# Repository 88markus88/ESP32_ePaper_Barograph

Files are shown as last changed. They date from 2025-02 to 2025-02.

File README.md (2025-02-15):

# ESP32 ePaper Barograph / Thermograph / Hydrograph
This project is an ESP32 based device that records and displays atmospheric pressure, temperature and humidity using a BME280 sensor and displays them as curves on an 4.2" B/W ePaper display. It operates from a LiPo battery which should be good for 3-6 months on one charge, and can be recharged via USB.
Basic features:
- 4.2" ePaper Display (I am using the display from WeAct, but others with 400x300 resolution are also possible)
- ESP32 Lolin32 Lite module for battery operation, with 1800 mAh LiPo battery intended for 3-6 months operation (not yet tested), charging via USB
- BME280 high quality sensor for pressure, temperature and humidity
- Curves for pressure, temperature, humidity in all combinations
- automatic adjustment of display with independent scales for all 3 measured paramters 
- Time scale can be switched "on the fly" between 21/36/72 hours, while retaining the data that fit into the newly selected time scale
- Tendency display (symbols and numeric) for all 3 measured parameters
- Buzzer can be added, to enable audible alert for large pressure changes and feedback when changing parameters via bluetooth
- Offset for altitude of observation can be enabled and adjusted
- Settings, after activation with button, via bluetooth
- 3D printed housing

## Pictures
Some pictures of the housing and the screen:

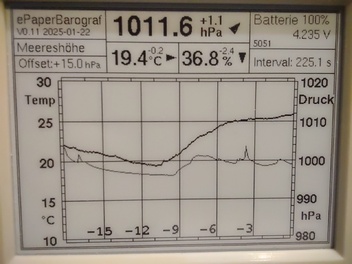
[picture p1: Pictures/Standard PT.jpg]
Display

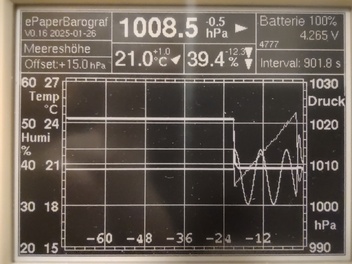
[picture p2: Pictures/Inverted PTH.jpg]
Inverted display

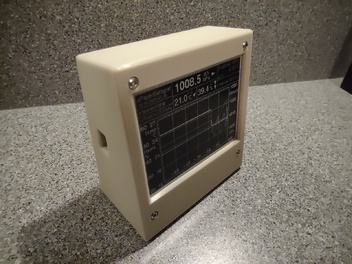
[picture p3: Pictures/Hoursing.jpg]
Housing


## Parts
The project presently supports two devices:
### Lolin32 Lite ESP32 module 
With 4.2" WeAct Display, BME 280 sensor module, 1800 mAh LiPo battery and 3d printed housing. A PCB board is also available.
   The following parts are needed:
   - [Lolin32 Lite ESP32 module](https://www.amazon.de/AZDelivery-LOLIN32-Bluetooth-kompatibel-Arduino/dp/B086V8X2RM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)
   - [BME 280 Module 3.3V](https://www.amazon.de/s?k=bme280&ref=404_search) Make sure that you get a module with 4 pins (6 pins would also work, but not fit into the housing), and from a reliable supplier. Beware: there are many cheap boards on Ebay that in reality do not contain a BME280 (square chip housing), but a BMP280 (rectangular chip housing)
   - [1800 mAh LiPo Battery 52x34x10 mm with JST-PH 2.0 connector](https://www.ebay.de/itm/255510046348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) Other LiPo batteries will also work, but likely not fit into the housing. **ATTENTION** for whatever reason the +/- on the Lolin32 Lite board are not identical to the polarity of most available batteries. **Do not use as delivered, you will likely fry the board!** With a needle you can unlatch the pins in the JST connector, pull out the pins and insert them again in reverse order.
   - JST PH 2.0 ( male & female) connectors. Connectors alsready configured with cables can be used.
   - [4.2" ePaper display module by WeAct](https://de.aliexpress.com/w/wholesale-Weact-studio-ePaper-4.2.html?spm=a2g0o.detail.search.0) 
   - [Elecrow CrowPanel](https://www.elecrow.com/wiki/CrowPanel_ESP32_E-paper_4.2-inch_HMI_Display.html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) with 4.2" ePaper display and BME280 sensor connected to the exposed GPIO pins.
   - 2 Resistors 200 KOhm
   - 1 Pushbutton for hole diameter 7mm
DS18B20, buzzer, transistor are presently not supported and not needed, but can be attached to the PCB
### Elecrow CrowPanel 4.2" ePaper
  - [Elecrow CrowPanel 2.2" e-paper HMI display](https://m.elecrow.com/pages/shop/product/details?id=207653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)
  - [BME 280 Module 3.3V](https://www.amazon.de/s?k=bme280&ref=404_search) Make sure that you get a module with 4 pins (6 pins would also work, but not fit into the housing), and from a reliable supplier. Beware: there are many cheap boards on Ebay that in reality do not contain a BME280 (square chip housing), but a BMP280 (rectangular chip housing). Cables and 2.54 mm pinheader for electrical connection.
   - LiPo Battery 3.7V with Micro JST 1.0 connector. Unfortunately Elecrow has chosen a tiny connector which is rarely used with LiPo batteries. I could not find a battery that comes with this connector, you will have to order battery and connector separately.

## Schematics and PCB
### Lolin32 Lite
I have created a PCB for the project, for use with the Lolin32 Lite module. It permits to connect the Lolin32 Lite module, ePaper, BME280 and battery connectors. It is also possible to add up to 2 DS18B20 temperature sensors and a piezo beeper - both not presently supported by the software. GPIO pins that are not directly used are exposed on a separate connector.
Gerber files are included in this project.
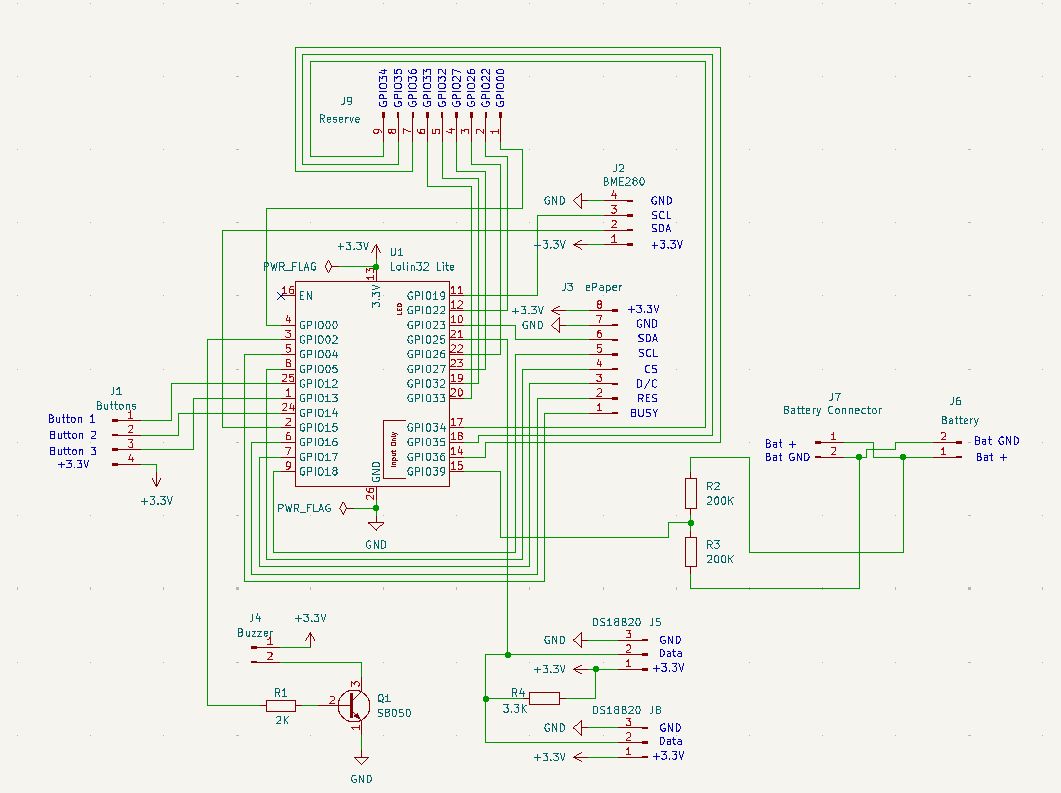
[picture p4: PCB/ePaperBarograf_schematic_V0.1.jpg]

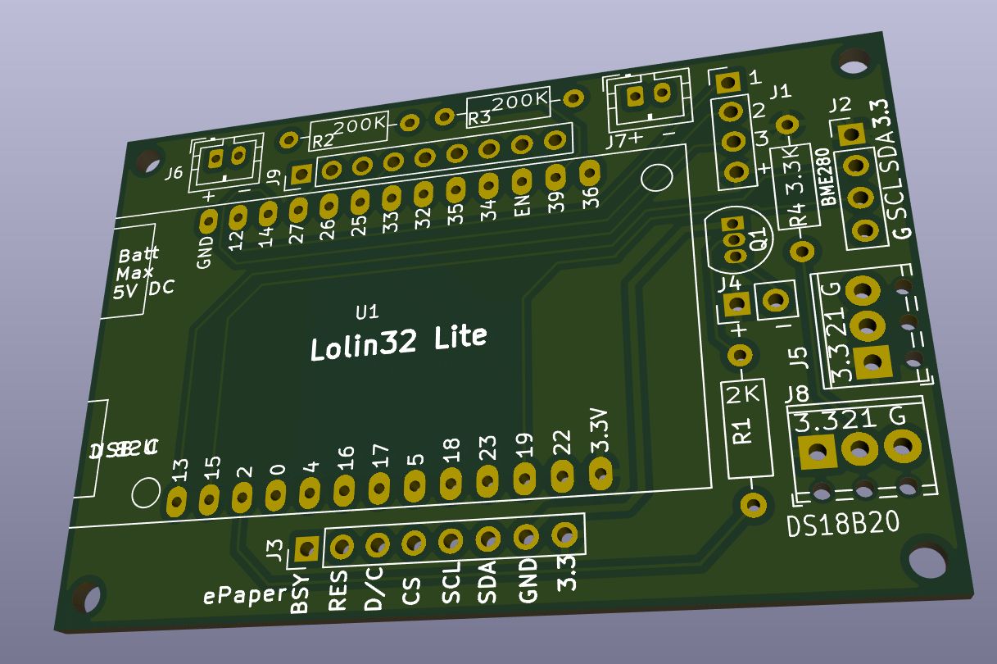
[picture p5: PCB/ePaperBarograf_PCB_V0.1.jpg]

### Elecrow CrowPanel 4.2" ePaper
This handy device can be used as is, with these addtions:
- BME280 (3.3V version) has to be connected via the connector on top to 3.3V, GND and SDA (GPIO15)/ SCL (GPIO19)
- LiPo battery can be connected via "Battery" connector on the left side of the housing. This is optional, without battery you need to keep the system permanently connected to power via USB - with every power loss the history data, which are kept in "RTC memory" are lost. 

## Software
### Software Structure
The software consists of 3 main components, which are located in three .cpp files
1. Control (ePaperBarograf.cpp): Timing, preferences storage, measurement, data storage & recalculations, hibernation
2. Graphics (ePaperGraphics.cpp): Graphics functions for ePaper display
3. Bluetooth configuration (ePaperBluetooth.cpp): Serial Bluetooth functions for adjustment of settings. Serial Bluetooth can only be used with the Lolin32 Lite - the CrowPanel has an ESP32S3 which only supports Bluetooth Low Energy (BLE).
4. BLE configuation - presently experimental and not yet functional
### Libraries
- OneWire                  : needed for BME280
- Arduino Unified Sensor   : needed for BME280
- Arduino BME280           : needed for BME280
- GxEPD2                   : ePaper Graphics
- Dallas Temperature       : DS18B20 temperature sensor
- u8g2 for Adafruit        : Fonts
### Building the Software
The software is written in C++, platform is Arduino and development environment is Platformio with VSCode. 
platformio.ini contains two development environments:
- env:Lolin32Lite_ePaper - this is the environment used for the Lolin32 Lite with separate 4.2" ePaper and battery. 
- env:CrowPanel_42 - this is the environment used for the Elecrow CrowPanel 4.2" ePaper.
Just connect your ESP32 to the computer via USB, select the env for the system you are building for and start the build. Platformio will automatically load the libraries that are needed and upload the firmware via USB Port. 
Switching of environments is done by clicking on the "env:..." entry in the lower status bar of VSCode, and then selecting the environment in the list that is displayed on top. Switching takes a few seconds.
Note that two versions of the hardware board are used, which have slightly different pinouts. Inparticular, in prototypes with hand mande board GPIO 35 is used for measurement of the battery voltage. In the newer printed circuit boards, GPIO 39 is used. This must be taken into account by setting either -D HANDMADE_BOARD or -D PCB_BOARD in [env] section within platformio.ini. Just comment out the part not needed.
### Starting the Barograph
After final assembly and test of all parts the software needs to be flashed on the ESP32. This is done by connecting the device the deveopment computer via USB cable and using the "Build" feature of platformio.
Once the software has been flashed, it will begin to operate directly:
- Default parameters are written into the ESP32 preferences memory (flash), which survies power down and even flashing of a new sofware version
- Test data are created, stored in RTC memory and displayed. They consist of artificial curves, which are easy to recognize and overwritten by real measured data as they are created. Complete overwrite of all test data takes 21 hours in default settings, up o 84 hours if the maximum time setting is used. 
Note that RTC memory content survives the sleep period between two measurements, but not power down (battery disconnected) or flashing of new software
- The barograf will then start routine operation- In default settings the measuring range is 18 hours, Pressure, Temperature and Humidiy are displayed. If more than 1 curve is shown, each has it's own scale. he further right a scale is on the screen, the thicker the corresponding curve If, e.g., Pm T and H are displayed, the pressure curve is 3 pixels, the temperature curve 2 pixels and the humidity curve one pixel.
### Settings
Settings are adjusted via Bluetooth connection. There is no special app for this, please use a bluetooth terminal on a mobile device with Bluetooth. A good tool for this is the [Serial Bluetooth Terminal by Kai Morich](https://play.google.com/store/apps/details?id=de.kai_morich.serial_bluetooth_terminal&hl=de)
This is how it is done:
- The Barograf is set into settings mode by presing the button. A corresponding message is shown on the screen
- Connect the mobile device to the barograph using the bluetooth settings. This has to be done only once
- Connect the Bluetooth terminal to the barograph, using the list of available devices in the "Hamburger" menu
- The barograph will then send a list of available commands 
- Enter the desired command. 
Examples: 
ATI to invert the display
ATC,1 to enable pressure correction (add the correction value)
ATX to leave the bluetooth settings and restart measurements
- Exit bluetooth settings 
If no command is given, the barograph will revert to measurement mode after 60 seconds
## Open topics
- BLE functionality to allow setting of parameters for CrowPanel
- Bluetooth setting for Lolin32 Lite is presently only possible via Bluetooth terminal on a mobile device. Create App or BLE web page to allow easier configuration

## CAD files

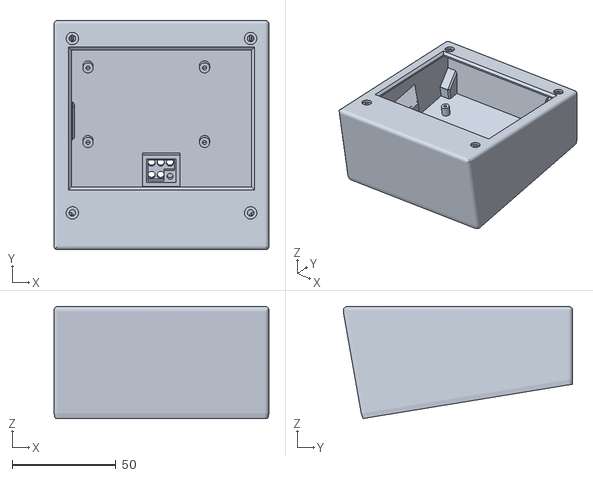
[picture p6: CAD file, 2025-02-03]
STL/Wetterstation WeAct epaper 4.2 v23.stl
103.8 x 110.8 x 54.1

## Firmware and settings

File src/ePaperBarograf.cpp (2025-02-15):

/****************************************************************/
// ePaperBarograf by. M. Preidel
/****************************************************************/

#include <Arduino.h>
#include <math.h>

//**** ESP32 sleep and rtc memory (which survives deep sleep)
#include "esp_sleep.h"
#include "driver/rtc_io.h"

//*** libs and defines for BME280
#include <Wire.h>
#include <Adafruit_Sensor.h>
#include <Adafruit_BME280.h>

// *** lib for permanent data storage in EEPROM
// https://randomnerdtutorials.com/esp32-save-data-permanently-preferences/
// if these defines are set, preferences are written / saved to eeprom. 
// otherwise just from RTC storage (survives deep sleep)
#define WRITE_PREFERENCES
#define WRITE_PREFS_INTERVAL 250 // store counters into preferences every <x> run
#define READ_PREFERENCES
#include <Preferences.h>
Preferences preferences; // object for preference storage in EEPROM
#define prefIDENT "barograf1"

// header file mit #defines, forward declarations, "extern" declarations von woanders deklarierten globalen var's
// globale variablen und alle anderen #includes sind im .cpp file
#include "ePaperBarograf.h"
#include "global.h" // global stuff from other modules

//************ push button stuff *****************/
struct Button {
  const uint8_t PIN;
  uint32_t numberKeyPresses;
  bool pressed;
};

#ifdef isPushButtons
  #ifdef LOLIN32_LITE
    #define BUTTON1 GPIO_NUM_12   // upper black button
    #define BUTTON2 GPIO_NUM_14  // middle red button
    #define BUTTON3 GPIO_NUM_13  // lower red  button
  #endif
  #ifdef CROW_PANEL  
    #define BUTTON1 GPIO_NUM_2  // upper button MENU
    #define BUTTON2 GPIO_NUM_1  // lower button EXIT
    #define BUTTON3 GPIO_NUM_5  // button CONFIRM at rotary switch
    #define BUTTON4 GPIO_NUM_4  // button DOWN at rotary switch
    #define BUTTON5 GPIO_NUM_6  // button DOWN at rotary switch
  #endif  
  volatile Button button1 = {BUTTON1, 0, false};
  volatile Button button2 = {BUTTON2, 0, false};
  volatile Button button3 = {BUTTON3, 0, false};

  void ARDUINO_ISR_ATTR button1Handler();
  void ARDUINO_ISR_ATTR button2Handler();
  void ARDUINO_ISR_ATTR button3Handler();
#endif // isPushButtons

// GPIO definition for battery voltage reading
#ifdef HANDMADE_BOARD
  #define VOLTAGE_PIN 35
#endif 
#ifdef PCB_BOARD
  #define VOLTAGE_PIN 39
#endif 

// GPIO definition for buzzer
#define BUZZER_PIN 2

// 08.01.25: store these variables in RTC memory, which survives deep sleep. 
RTC_DATA_ATTR uint32_t startCounter = 0;    // total counter for starts of ESP32
RTC_DATA_ATTR uint32_t dischgCnt = 0;    // counter for starts of ESP32 since last charge
RTC_DATA_ATTR uint32_t prevMicrovolt = 0;
RTC_DATA_ATTR float prevVoltage = 0;
float prefs[4] = {0.0, 0.0, 0.0, 0.0};  // storage for preferences

float volt, percent;                    // battery voltage and percent fill degree

uint32_t multiplier = MULTIPLIER_FULL;  // slepp time multiplier (standard is 1 min, this multiplier is applied to that)
//uint32_t targetSleepSec;                // target sleep time in seconds
uint32_t targetSleepUSec;               // target sleep time in microseconds

char outstring[maxLOG_STRING_LEN];      // for serial and other debug output

Adafruit_BME280 bme;                    // BME280 sensor I2C
float temperature = 0;                  // data read by BME280
float humidity = 0;
float pressure = 0;


//----------------------- measurement data variables -----------------------
uint32_t startTimeMillis; 
uint32_t measTimeMillis;

// measurement data

#define createTestData          // flag to create test data at setup, overwriting whatever may be there

// measurement data, stored in RTC memory which survives the deep sleep. ESP32 has 8 K, used for this 5448 Bytes
RTC_DATA_ATTR measurementData wData;

// screen colors
RTC_DATA_ATTR uint32_t fgndColor;
RTC_DATA_ATTR uint32_t bgndColor;

// determine after how many partial updates a full update of the epaper is to be done
// 1: always full update
#ifdef LOLIN32_LITE
  #define FULL_UPDATE_INTERVAL  10
#endif
#ifdef CROW_PANEL
  #define FULL_UPDATE_INTERVAL  1
#endif

/**************************************************!
   @brief    buzzer()
   @details  Function to create a buzzer sound
   @param    uint16_t number    : how many buzzes
   @param    uint16_t duration : how long in ms for every buzz
   @param    uint16_t interval : how long in ms between buzzes
   @return   void
***************************************************/
void buzzer(uint16_t number, uint16_t duration, uint16_t interval)
{
  uint16_t i;
  for(i=0; i<number; i++){
    logOut(3, (char*)"Start Buzzer");
    pinMode(BUZZER_PIN, OUTPUT);
    digitalWrite(BUZZER_PIN, HIGH);
    delay(duration);
    digitalWrite(BUZZER_PIN, LOW);
    delay(interval);
    logOut(3, (char*)"End of Buzzer");
  }  
}    

/**************************************************!
   @brief    logOut()
   @details  Function create log output
   @return   void
***************************************************/
void logOut(int logLevel, char* str)
{
  char safeStr[maxLOG_STRING_LEN+10];
  static uint32_t logCnt = 0;
  // for safety: ensure zero termination well before the end of the string
  // crashes with static strings.
  // str[maxLOG_STRING_LEN-1]=0;
  if(logLevel <= logLEVEL){
    strncat(safeStr, str, maxLOG_STRING_LEN-1); // copy limited number of characters only
    sprintf(safeStr,"%ld %s",logCnt,str);
    //Serial.println(str);
    Serial.println(safeStr);
    logCnt++;
  }
}

/**************************************************!
   @brief    Function to read the BME280 data 
   @details  The BME280 data is read in 
   @return   void
***************************************************/
void getBME280SensorData() 
{
  // Only needed in forced mode! Forced mode lets the sensor sleep between measurements.
  // normal mode: sensor warming +1,5°C vs. DS18B20. Forced mode: +0,9°C
  bme.takeForcedMeasurement(); // has no effect in normal mode

  pressure = bme.readPressure()/100;
  sprintf(outstring,"Pressure: %3.1f mBar ", pressure);
  logOut(2, outstring);
  humidity = bme.readHumidity();
  sprintf(outstring,"Humidity: %3.1f %% ", humidity);
  logOut(2, outstring);
  temperature = bme.readTemperature();
  sprintf(outstring,"Temperature: %3.1f °C \n", temperature);
  logOut(2, outstring);
}  // of method "getSensorData()"


/*************************** getBatteryCapacity ************************** */
int readBatteryVoltage(float* percent, float* volt)
{
  uint16_t readval;

  *percent = 100;
  pinMode(VOLTAGE_PIN, INPUT);
  readval = analogRead(VOLTAGE_PIN);// / 4096.0 * 7.23;      // LOLIN D32 (no voltage divider need already fitted to board.or NODEMCU ESP32 with 100K+100K voltage divider
  *volt= (float)readval / 4096.0 * 7.23;
  //float voltage = analogRead(39) / 4096.0 * 7.23;    // NODEMCU ESP32 with 100K+100K voltage divider added
  //float voltage = analogRead(A0) / 4096.0 * 4.24;    // Wemos / Lolin D1 Mini 100K series resistor added
  //float voltage = analogRead(A0) / 4096.0 * 5.00;    // Ardunio UNO, no voltage divider required
  
  *percent = 2808.3808 * pow(*volt, 4) - 43560.9157 * pow(*volt, 3) + 252848.5888 * pow(*volt, 2) - 650767.4615 * *volt + 626532.5703;
  
  if(*percent<0) *percent =0; // to ensure that the above formula does not produce negative values, as it does slightly above 3.5V

  if (*volt > 4.19) *percent = 100;
  else if (*volt <= 3.50) *percent = 0;

  sprintf(outstring," readval: %d Voltage: %3.2f Percent: %3.1f\n",readval, *volt,*percent);
  logOut(2,outstring);
  return(true);
}

/*************************  fillTestData ******************************************/
// fill the measurement arrays with arbitrary demo data to test graphics routine

void fillTestData()
{
  int i, j;
  float startval = 1017.0;
  float randomspread = 2.0;
  float cosrange = 5.0;

  logOut(2,(char*)"Filling test data");

  wData.pressHistoryMax= - 1000000;
  wData.pressHistoryMin=   1000000;
  wData.tempHistoryMax= - 1000000;
  wData.tempHistoryMin=   1000000;
  wData.humiHistoryMax=   0;      // unsigned integer
  wData.humiHistoryMin=   10000;

  // TEST - remove next 3 lines for working version. Overwrites preferences every time when recompiled!
  wData.targetMeasurementIntervalSec = d_measIntervalSec;
  wData.graphTimeRangeHours = d_timeRangeHours;
  wData.preferencesChanged = true;
  wData.indexFirstPointToDraw = offsetData72hGraph;
  wData.graphicsType = d_graphicsType;
  //if(wData.applyPressureCorrection) 
  //  wData.applyPressureCorrection = true;
  //  wData.pressureCorrValue = 15.0;
  gettimeofday(&wData.last2MeasurementTimestamp, NULL);    // get&set previous measurement time
  delay(2000);
  gettimeofday(&wData.lastMeasurementTimestamp, NULL);     // get&set act measurement time
  wData.lastTargetSleeptime = wData.targetMeasurementIntervalSec;
  wData.lastActualSleeptimeAfterMeasUsec = 0; // we have not slept yet. causes measurement ot be started immediately in doWork()
  delay(500);                                // this brings us beyond the 5 sec threshold in doWork()

  sprintf(outstring,"************** fill test data %d ********************\n", wData.dataPresent);
  logOut(2,outstring);
  for(i=0;i<noDataPoints;i++)
  {
    wData.ageOfDatapoint[i] = (noDataPoints-i) * wData.targetMeasurementIntervalSec; // default spacing: 15 min = 900 sec
    wData.pressHistory[i]= 994 + 40/(i+1);
    //wData.pressHistory[i]= 1030-(float)i/20;
    //wData.pressHistory[i]= startval+(float)cos((float)i/50)*cosrange + i/70 + randomspread*((float)rand()/ RAND_MAX - 1.5);
    if(wData.pressHistory[i] > wData.pressHistoryMax) 
        wData.pressHistoryMax = wData.pressHistory[i];
    if(wData.pressHistory[i] < wData.pressHistoryMin) 
        wData.pressHistoryMin = wData.pressHistory[i];    

    wData.tempHistory[i] = 20 + 2*sin((float)i/20);
    if(wData.tempHistory[i] > wData.tempHistoryMax) 
        wData.tempHistoryMax = wData.tempHistory[i];
    if(wData.tempHistory[i] < wData.tempHistoryMin) 
        wData.tempHistoryMin = wData.tempHistory[i]; 

    wData.humiHistory[i] = int(10.0*(35.5 + 20 * i / noDataPoints+ randomspread*((float)rand()/ RAND_MAX - 1.5))); 
    if(wData.humiHistory[i] > wData.humiHistoryMax) 
        wData.humiHistoryMax = wData.humiHistory[i];
    if(wData.humiHistory[i] < wData.humiHistoryMin) 
        wData.humiHistoryMin = wData.humiHistory[i];      
  }

  sprintf(outstring,"Min/Max Tstdata: P: %3.1f-%3.1f T:  %3.1f-%3.1f H: %d-%d", 
        wData.pressHistoryMin, wData.pressHistoryMax,  wData.tempHistoryMin,  wData.tempHistoryMax,
        wData.humiHistoryMin, wData.humiHistoryMax);
  logOut(2,outstring);  
  sprintf(outstring,"Tstdata: Time: %ld.%06ld sec", 
        wData.lastMeasurementTimestamp.tv_sec, wData.lastMeasurementTimestamp.tv_usec);
  logOut(2,outstring);  

  // 3 hour pressure change value: minus 3h = 12 data points at 15 min per point
  wData.pressure3hChange = wData.pressHistory[noDataPoints-1]-wData.pressHistory[noDataPoints-1-12];
  wData.humidity3hChange = wData.humiHistory[noDataPoints-1]-wData.humiHistory[noDataPoints-1-12];
  wData.temperature3hChange=wData.tempHistory[noDataPoints-1]-wData.tempHistory[noDataPoints-1-12];

  // actual data for initial display
  wData.actPressureRaw = wData.pressHistory[noDataPoints-1];
  wData.actPressureCorr= wData.actPressureRaw + wData.pressureCorrValue;
  wData.actHumidity    = wData.humiHistory[noDataPoints-1];
  wData.actTemperature = wData.tempHistory[noDataPoints-1];

  // set marker for "data present" to avoid calling this function again.
  wData.dataPresent = true;

  //set marker for "just initialized"
  wData.justInitialized = true;
}

/**************************************************!
   @brief    Function to calculate the pressure, temperature,humdity change during the last 3 hours 
   @details  using the time information in wData.ageOfDatapoint[i]
   @return   void
***************************************************/
void calc3HourChanges()
{
  int i, marker;
  uint32_t threeHourMark = 3*3600;
  float newP, oldP, oldT, newT, oldH, newH;

  for (i=noDataPoints-1; i>0; i--)
  {
    if ((wData.ageOfDatapoint[i]-threeHourMark) < wData.targetMeasurementIntervalSec/2)
    {
      marker=i;
      break;
    }
  }

  //calculate average over three data points for now and three hours ago, changed to only one last point
  oldP = (wData.pressHistory[marker-1] + wData.pressHistory[marker] + wData.pressHistory[marker+1])/3;
  //newP = (wData.pressHistory[noDataPoints-1]+wData.pressHistory[noDataPoints-2]+wData.pressHistory[noDataPoints-3])/3;
  newP = wData.pressHistory[noDataPoints-1];
  wData.pressure3hChange =  newP - oldP;

  //same for humidity
  oldH = (wData.humiHistory[marker-1] + wData.humiHistory[marker] + wData.humiHistory[marker+1])/3;
  // newH = (wData.humiHistory[noDataPoints-1]+wData.humiHistory[noDataPoints-2]+wData.humiHistory[noDataPoints-3])/3;
  newH = wData.humiHistory[noDataPoints-1];
  wData.humidity3hChange =  (float)(newH - oldH)/10.0;

  //and temperature
  oldT = (wData.tempHistory[marker-1] + wData.tempHistory[marker] + wData.tempHistory[marker+1])/3;
  //newT = (wData.tempHistory[noDataPoints-1]+wData.tempHistory[noDataPoints-2]+wData.tempHistory[noDataPoints-3])/3;
  newT = wData.tempHistory[noDataPoints-1];
  wData.temperature3hChange =  newT - oldT;

  //previous simplified method, on point and assuming 900 sec per data point
  //wData.pressure3hChange = wData.pressHistory[noDataPoints-1]-wData.pressHistory[noDataPoints-1-12];
  sprintf(outstring, "3h:%d t:%ld Pold:%3.2f Pnew:%3.2f 3hC:%3.3f Told:%3.2f, Tnew:%3.2f 3hC:%3.3f Hold:%3.2f Hnew:%3.2f 3hC:%3.3f\n",
      marker, wData.ageOfDatapoint[marker], 
      oldP, newP, wData.pressure3hChange, 
      oldT, newT, wData.temperature3hChange,
      oldH, newH, wData.humidity3hChange);
  logOut(2,outstring);    
}

/**************************************************!
   @brief    output the stored data
   @details  intended to check the work of the data timescale change functions
   @param    l_idx, u_idx: control start and end ranges
   @return   void
***************************************************/
void outputStoredData(uint16_t l_idx, uint16_t u_idx)
{
  int i; 

  for(i=0;i<noDataPoints;i++){
    if(i <= l_idx || i >= u_idx){
      //sprintf(outstring,"i: %d, age %ld time_sec: %ld P: %3.1f T: %3.1f H: %3.1f",
      sprintf(outstring,"i: %d, age %ld P: %3.1f H: %d H: %3.1f",
        i, wData.ageOfDatapoint[i], //wData.timestampSecondsOfDataPoint[i],
        wData.pressHistory[i], wData.humiHistory[i], wData.tempHistory[i]);
      logOut(2,outstring)  ;
    }  
  }

}

/**************************************************!
   @brief    quarterMeasurementScale() : 84->21
   @details  Adapting the stored measurement data and the measurement interval
   @param
   @return   void
***************************************************/
void quarterMeasurementScale()
{
  int16_t i, idx;
  uint32_t interv;

  sprintf(outstring,"Before quarterMScale: wData.targetMeasurementIntervalSec: %ld",  wData.targetMeasurementIntervalSec);
  logOut(2,outstring);

  //outputStoredData(5, noDataPoints-5); // limited ouput
  outputStoredData(noDataPoints, 0);   // output all 

  // adapt measurement interval
  wData.targetMeasurementIntervalSec = wData.targetMeasurementIntervalSec/4; // controls proper time planning
  wData.lastTargetSleeptime = wData.targetMeasurementIntervalSec;            // to ensure proper time planning for next measurement 
  wData.actSecondsSinceLastMeasurement = wData.actSecondsSinceLastMeasurement/4; // only for display
  wData.lastActualSleeptimeAfterMeasUsec = wData.lastActualSleeptimeAfterMeasUsec/4; // needed for sleep time calculation
  wData.lastActualSleeptimeNotMeasUsec   = wData.lastActualSleeptimeNotMeasUsec /4;  // needed for sleep time calculation
  interv =  wData.targetMeasurementIntervalSec;
  idx=0;
  for(i=3*noDataPoints/4; i<noDataPoints; i++){
    if(idx<30 || idx > (noDataPoints-10))
    {
      sprintf(outstring, "idx: %d i: %d age[idx, i] %ld %ld: P[idx, i]: %3.1f %3.1f", 
        idx, i, wData.ageOfDatapoint[idx], wData.ageOfDatapoint[i],
        wData.pressHistory[idx], wData.pressHistory[i]);
      logOut(2,outstring);
    }  
    wData.ageOfDatapoint[idx]             = wData.ageOfDatapoint[i];
    //wData.timestampSecondsOfDataPoint[idx]= wData.timestampSecondsOfDataPoint[i];
    wData.pressHistory[idx]               = wData.pressHistory[i];
    wData.humiHistory[idx]                = wData.humiHistory[i];
    wData.tempHistory[idx]                = wData.tempHistory[i];
    idx++;
    wData.ageOfDatapoint[idx]             = wData.ageOfDatapoint[i] + interv;
    //wData.timestampSecondsOfDataPoint[idx]= wData.timestampSecondsOfDataPoint[i];
    wData.pressHistory[idx]               = wData.pressHistory[i];
    wData.humiHistory[idx]                = wData.humiHistory[i];
    wData.tempHistory[idx]                = wData.tempHistory[i];
    idx++;
    wData.ageOfDatapoint[idx]             = wData.ageOfDatapoint[i] + 2 * interv; 
    //wData.timestampSecondsOfDataPoint[idx]= wData.timestampSecondsOfDataPoint[i];
    wData.pressHistory[idx]               = wData.pressHistory[i];
    wData.humiHistory[idx]                = wData.humiHistory[i];
    wData.tempHistory[idx]                = wData.tempHistory[i];
    idx++;
    wData.ageOfDatapoint[idx]           = wData.ageOfDatapoint[i] + 3 * interv;
    //wData.timestampSecondsOfDataPoint[idx]= wData.timestampSecondsOfDataPoint[i];
    wData.pressHistory[idx]               = wData.pressHistory[i];
    wData.humiHistory[idx]                = wData.humiHistory[i];
    wData.tempHistory[idx]                = wData.tempHistory[i];
    idx++;    
  }

  // correct nominal ages of data points, required for graphics display - correct x axis
  idx = 0;
  for(i=(noDataPoints-1); i>=0 ; i--){
     wData.ageOfDatapoint[i] = idx * wData.targetMeasurementIntervalSec;
     idx++;
     //sprintf(outstring,"i: %d idx: %d", i, idx);
     //logOut(2,outstring);
  } 

  sprintf(outstring,"After quarterMScale: wData.targetMeasurementIntervalSec: %ld",  wData.targetMeasurementIntervalSec);
  logOut(2,outstring);
  //outputStoredData(5, noDataPoints-5); // limited ouput
  outputStoredData(noDataPoints, 0);   // output all 
}

/**************************************************!
   @brief    halfMeasurementScale() : 42->21 or 84->42h
   @details  Adapting the stored measurement data and the measurement interval
   @param
   @return   void
***************************************************/
void halfMeasurementScale()
{
  int16_t i, idx;
  uint32_t interv;

  sprintf(outstring,"Before halfMScale: wData.targetMeasurementIntervalSec: %ld",  wData.targetMeasurementIntervalSec);
  logOut(2,outstring);
  //outputStoredData(5, noDataPoints-5); // limited ouput
  outputStoredData(noDataPoints, 0);   // output all 

  // adapt measurement interval
  wData.targetMeasurementIntervalSec = wData.targetMeasurementIntervalSec/2; // controls proper time planning
  wData.lastTargetSleeptime = wData.targetMeasurementIntervalSec;            // to ensure proper time planning for next measurement 
  wData.actSecondsSinceLastMeasurement = wData.actSecondsSinceLastMeasurement/2; // only for display
  wData.lastActualSleeptimeAfterMeasUsec = wData.lastActualSleeptimeAfterMeasUsec/2; // needed for sleep time calculation
  wData.lastActualSleeptimeNotMeasUsec   = wData.lastActualSleeptimeNotMeasUsec /2;  // needed for sleep time calculation
  interv =  wData.targetMeasurementIntervalSec;
  idx=0;
  for(i=noDataPoints/2; i<noDataPoints; i++){
    if(idx<15 || idx > (noDataPoints-10))
    {
      sprintf(outstring, "idx: %d i: %d age[idx, i] %ld %ld: P[idx, i]: %3.1f %3.1f", 
        idx, i, wData.ageOfDatapoint[idx], wData.ageOfDatapoint[i],
        wData.pressHistory[idx], wData.pressHistory[i]);
      logOut(2,outstring);
    }  
    wData.ageOfDatapoint[idx]             = wData.ageOfDatapoint[i];
    //wData.timestampSecondsOfDataPoint[idx]= wData.timestampSecondsOfDataPoint[i];
    wData.pressHistory[idx]               = wData.pressHistory[i];
    wData.humiHistory[idx]                = wData.humiHistory[i];
    wData.tempHistory[idx]                = wData.tempHistory[i];
    idx++;
    wData.ageOfDatapoint[idx]             = wData.ageOfDatapoint[i] + interv;
    //wData.timestampSecondsOfDataPoint[idx]= wData.timestampSecondsOfDataPoint[i];
    wData.pressHistory[idx]               = wData.pressHistory[i];
    wData.humiHistory[idx]                = wData.humiHistory[i];
    wData.tempHistory[idx]                = wData.tempHistory[i];
    idx++;
  }

  // correct nominal ages of data points, required for graphics display - correct x axis
  idx = 0;
  for(i=noDataPoints-1; i>=0 ; i--){
     wData.ageOfDatapoint[i] = idx * wData.targetMeasurementIntervalSec;
     idx++;
  } 

  sprintf(outstring,"After halfMScale: wData.targetMeasurementIntervalSec: %ld",  wData.targetMeasurementIntervalSec);
  logOut(2,outstring);
  //outputStoredData(5, noDataPoints-5); // limited ouput
  outputStoredData(noDataPoints, 0);   // output all 
}
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
void loop() 
{
  int ret, ret1, ret2;
  char* cp;
  bool writing_counter_prefs = false;

  // clearScreenPartialUpdate();
  // clearScreenFullUpdate();
  doWork();

};

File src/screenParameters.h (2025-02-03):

//---------------------------- Screen parameters -----------------------------
#define SCREEN_WIDTH  400.0    // Set for landscape mode, don't remove the decimal place!
#define SCREEN_HEIGHT 300.0

//--------------------------- graphics parameters ----------------------------
// margin
#define extBW             2       // margin between screen border and outer box
#define numWXL            3       // left margin between graph and outer box
#define numWXR            44      // right marging between graph and o.box. Right number area
#define intBW             4       // width of border of the graph itself, with ticks
#define lowerBW           5       // margin between outer box and lower graph border
#define upperBW           6       // margin between upper text box and upper graph border
#define offsetPix72hGraph    48      // offset from left for 72 instead of 84 hour graph

// width of text on top
#define textLWidth        110     // left area: sea level, alt, cal. etc.
#define textMWidth        176     // middle area: pressure, temp, humidity
//#define textR1Width       50      // right area 1: pressure tendency graph and text
//#define textR2Width       60      // right area 2: battery symbol and %
#define textRWidth        109

// height  of text on top
#define infoHeight        75
#define pressureHeight    38
#define temperatureHeight 37
#define prognameHeight    35
#define levelHeight       20
#define corrHeight        20
#define batHeight         45
#define intervalHeight    30

// drawing canvas size, not including the borders. Actually available for drawing
#define canvasHeight      200
#define canvasWidth       337

#define canvasLeft      extBW + numWXL + intBW
#define canvasTop       extBW + infoHeight + upperBW + intBW

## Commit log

2025-02-03 Added housing
    [Wetterstation WeAct epaper 4.2 v23.stl]
2025-02-03 Added PCB
2025-02-03 Added PCB schematic
2025-02-05 V0.22 BLE included untested, print bugs squashd
    [ePaperBLE.cpp, ePaperBarograf.cpp, ePaperGraphics.cpp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]
